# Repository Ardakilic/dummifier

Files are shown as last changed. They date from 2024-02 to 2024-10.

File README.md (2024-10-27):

# Dummifier
Dummifier: A USB-3 to USB-2 with USB Type-C Port adapter where the the engineers fail to follow basic standards while designing the boards.

You just plug this dongle thingy between your device and your usb-c cable, and it'll start working as you expected.

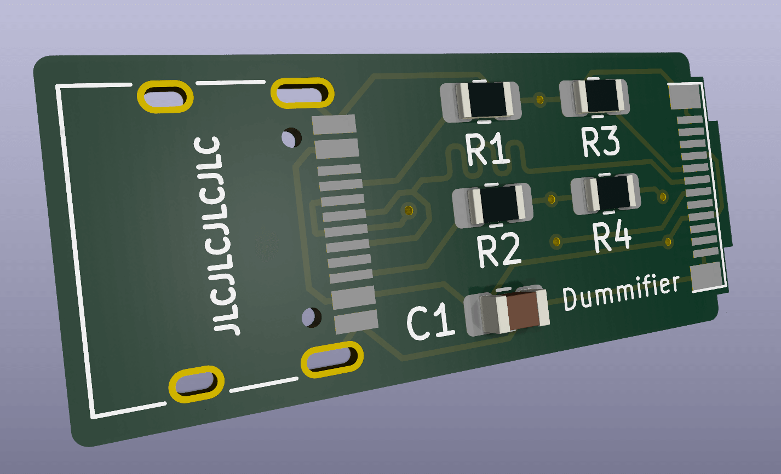
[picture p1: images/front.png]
Front image


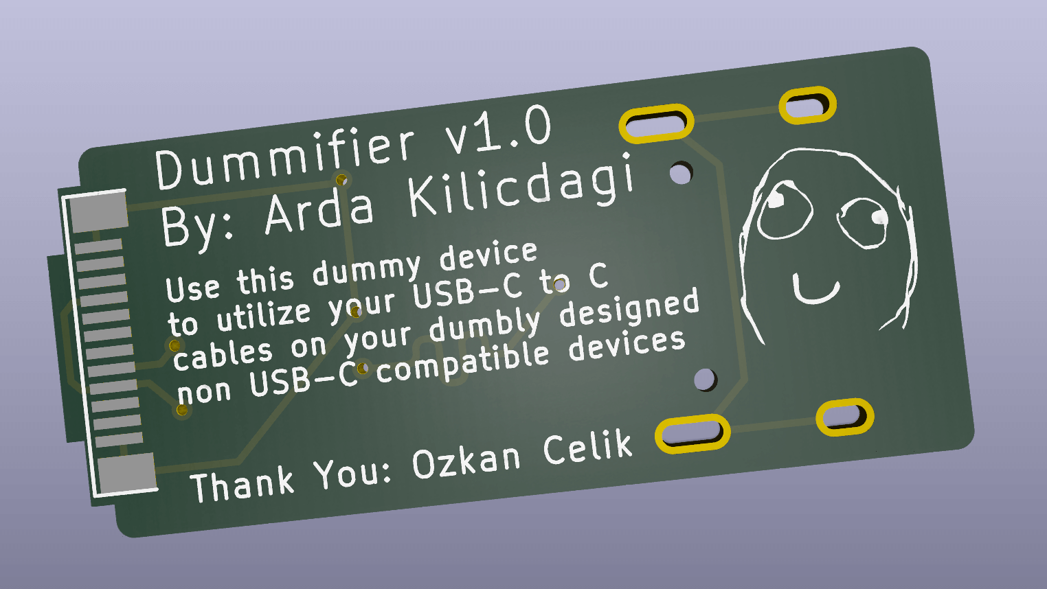
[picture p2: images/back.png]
Back image


# Why?

First of all, I needed this. Some devices that I own, such as [Planck keyboard](https://drop.com/buy/planck-mechanical-keyboard), [Anbernic RG351P](https://retrogamecorps.com/rg351/) utilized USB-C port, but they only worked when a cheap USB-C to USB-A cable was utilized, or through a USB Hub. They were not working at all with the USB-C cable I carry around, or getting wrong voltage and being burned. I burned my GP micro USB (I was using a USB-C to micro USB converter) battery charger because of this.

Additionally, I made some mods for Nintendo new 2DS XL for USB-C mod, and some cables were not working correctly.

Even newer Raspberry Pi Pico clones were having this issue.

The common workaround for this issue is using a USB Hub, or Cheap, non-standard, USB 2.0 Type A to USB-C 4 pin cables.

These cables are getting harder to find day by day.

I used to make some dummy cables for this purpose. Like [this](https://twitter.com/ardadev/status/1750195780932063600), [this](https://www.reddit.com/r/3DS/comments/whqvg9/made_a_usbc_converter_cable_that_works_with_usbc/) and [this](https://www.reddit.com/r/vitahacks/comments/uyd8oe/created_a_typec_adapter_for_my_vita_1000_that/). Functionality wise, they were all working, but damn they were ugly! Also, they had one thing in common. These populated 5.1K ohm resistors in CC1 and CC2 pins.

When I checked the [USB standards](https://www.usb.org/sites/default/files/USB%20Type-C%20Spec%20R2.0%20-%20August%202019.pdf) (page 38 and 76) , I realized these were necessary on female end so that the devices could talk to each other with USB 2.0 standards and get 5V instead of PD voltages.

After I burned my GP battery charger, I decided to tinker with Kicad and make my own adapter.

Some people even suggest using a [flex PCB mod that's soldered directly over the connector](https://github.com/ide/usb-c-to-c-power-mod) of these crappy designed devices, but this is not doable by everyone.

So, I decided I'd make a little converter like this. Anyone could use this. It's like a USB-C extension cable that you plug the male end to the bad device, and the female end to your favorite modern USB-C to USB-C cable.

I hope someone finds this helpful.

## Current status

* Tested, works nicely! Utilize only 5.1k resistors and 100nf cap (cap is optional). [Part from my Twitter flood, here](https://twitter.com/ardadev/status/1767934961703702860)
* Also, please be aware of the license of the project.

# Requirements

* Kicad 8
* If not set already, from PCB editor:
	* go to File / Board Setup
	* Set "Copper to Edge Clearance" to 0 (zero)

# TODOs

* Make VCC and GND lanes thicker.
* Export Gerber files directly for factory-ready printing.
* For better compatibility, [PCB design may need to be updated](https://www.reddit.com/r/UsbCHardware/comments/1ctkpf0/comment/l4fosnr/)

# Special Thanks

* [Ozkan Celik](https://github.com/ozkan). He helped me a lot during the design process and ideas.
* Ender Piyale, I gave him a lot of headache as well.
* Kazim Kaba, for case design.

# License
GNU GPL V3

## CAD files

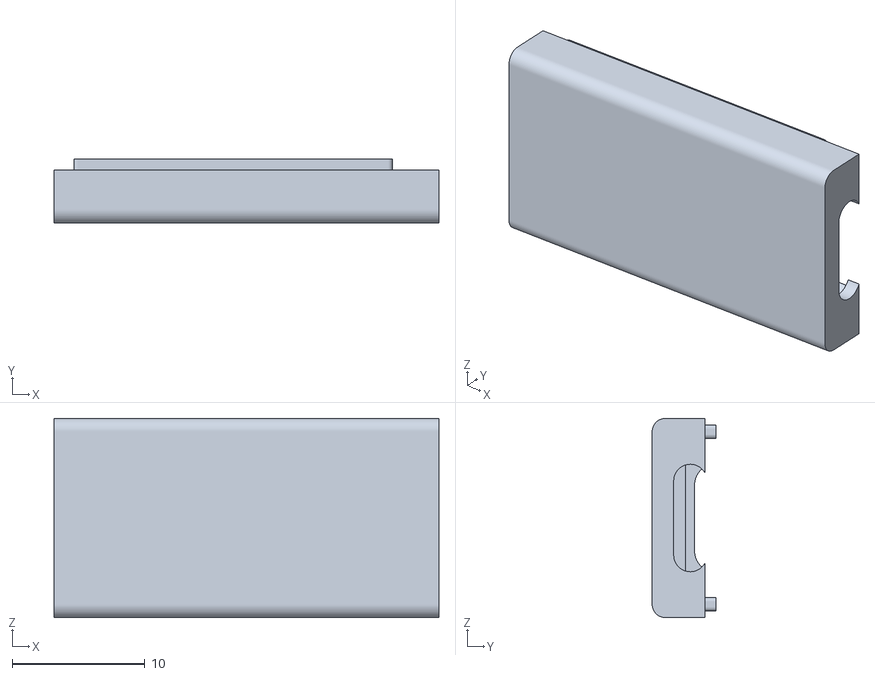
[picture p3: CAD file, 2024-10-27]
case/bottom.stl
29.0 x 4.80 x 15.0

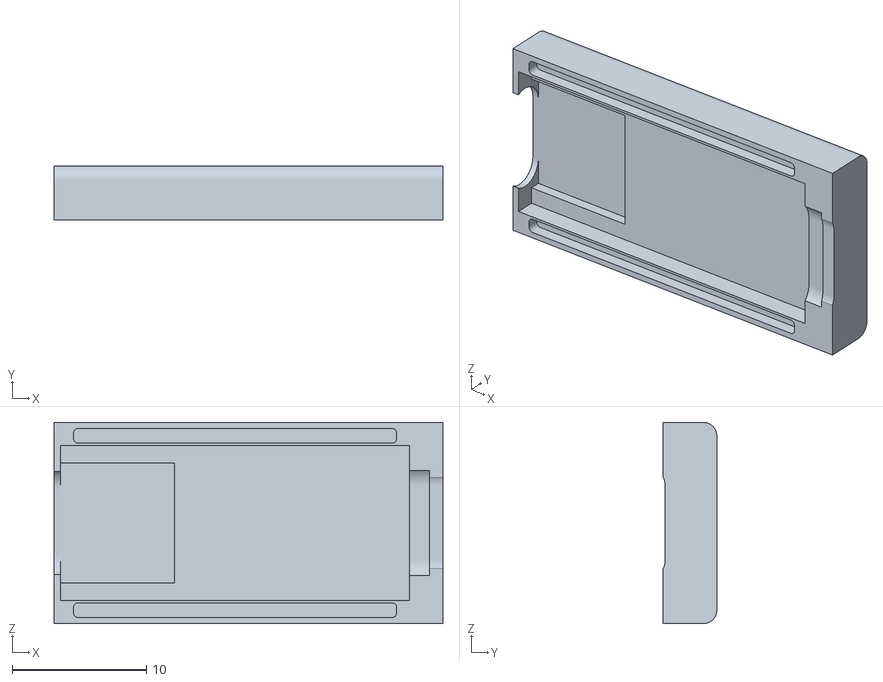
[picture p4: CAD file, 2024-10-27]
case/top.stl
29.0 x 4.00 x 15.0

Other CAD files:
case/case alt v4.f3d
case/cover.f3d

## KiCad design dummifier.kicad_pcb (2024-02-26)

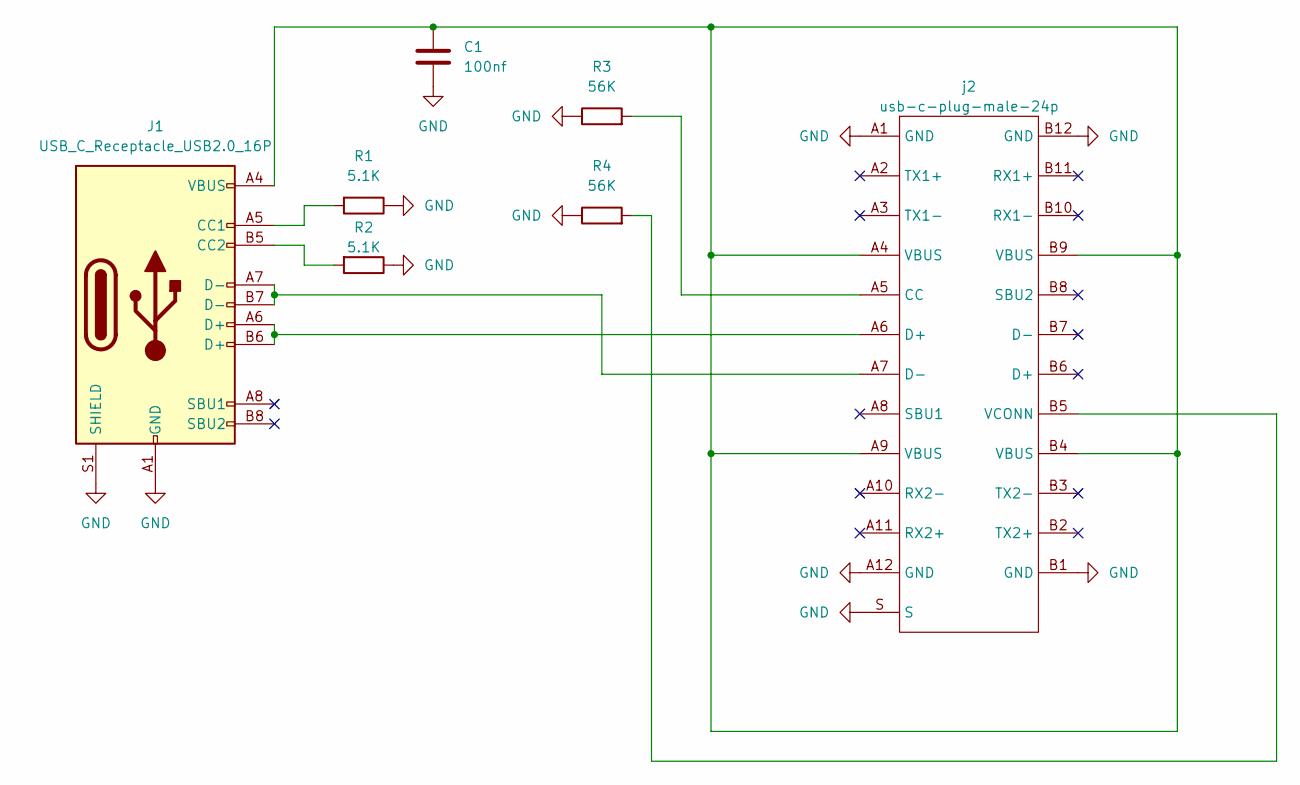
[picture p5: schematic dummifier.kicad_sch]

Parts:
C1: 100nf; C_0805_2012Metric_Pad1.18x1.45mm_HandSolder
J1: USB_C_Receptacle_USB2.0_16P; USB_C_Receptacle_HRO_TYPE-C-31-M-12
R1, R2: 5.1K; R_0805_2012Metric_Pad1.20x1.40mm_HandSolder
R3, R4: 56K; R_0805_2012Metric_Pad1.20x1.40mm_HandSolder
j2: usb-c-plug-male-24p; CONN_USBC-PLUG_24_PIN-2

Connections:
GND: C1.2, J1.A1 (GND), J1.A12 (GND), J1.B1 (GND), J1.B12 (GND), J1.S1 (SHIELD), R1.1, R2.1, R3.1, R4.1, j2.A1 (GND), j2.A12 (GND), j2.B1 (GND), j2.B12 (GND), j2.S
unnamed: C1.1, J1.A4 (VBUS), J1.A9 (VBUS), J1.B4 (VBUS), J1.B9 (VBUS), j2.A4 (VBUS), j2.A9 (VBUS), j2.B4 (VBUS), j2.B9 (VBUS)
unnamed: J1.A5 (CC1), R1.2
unnamed: J1.B5 (CC2), R2.2
unnamed: J1.A6 (D+), J1.B6 (D+), j2.A6 (D+)
unnamed: J1.A7 (D-), J1.B7 (D-), j2.A7 (D-)
unnamed: R3.2, j2.A5 (CC)
unnamed: R4.2, j2.B5 (VCONN)

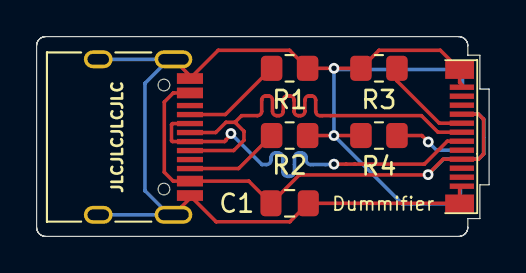
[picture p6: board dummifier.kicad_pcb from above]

Board: 2 copper layers, 25.1 x 11.1 mm, 7 parts (0 on the bottom side), 8 nets.

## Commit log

2024-02-26 feature: upload the KiCad project file
    [dummifier.kicad_pcb, dummifier.kicad_sch]
2024-02-27 feature: Add Gerber files for v1.0
    [dummifier-B_Cu.gbl, dummifier-B_Mask.gbs, dummifier-B_Paste.gbp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]
2024-10-27 feature: outer case design and outputs added
    [bottom.stl, case alt v4.f3d, cover.f3d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]
